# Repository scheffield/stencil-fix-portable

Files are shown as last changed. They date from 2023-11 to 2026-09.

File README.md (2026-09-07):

# Stencil Fix Portable

Stencil Fix Portable YouTube video (https://youtu.be/Am3ztQIkss0 "Stencil Fix Portable")

## Assembly
Perfboard top view
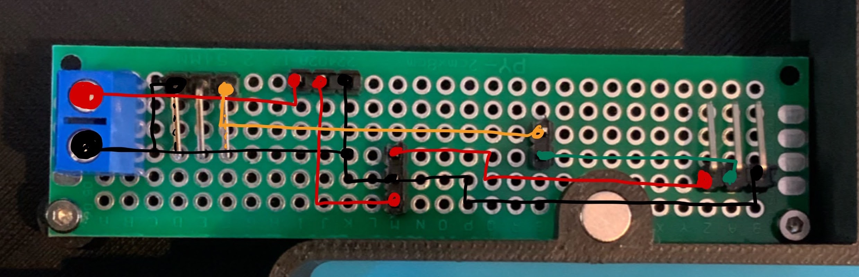
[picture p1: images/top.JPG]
Top view

View when soldering (flipped from the top view)
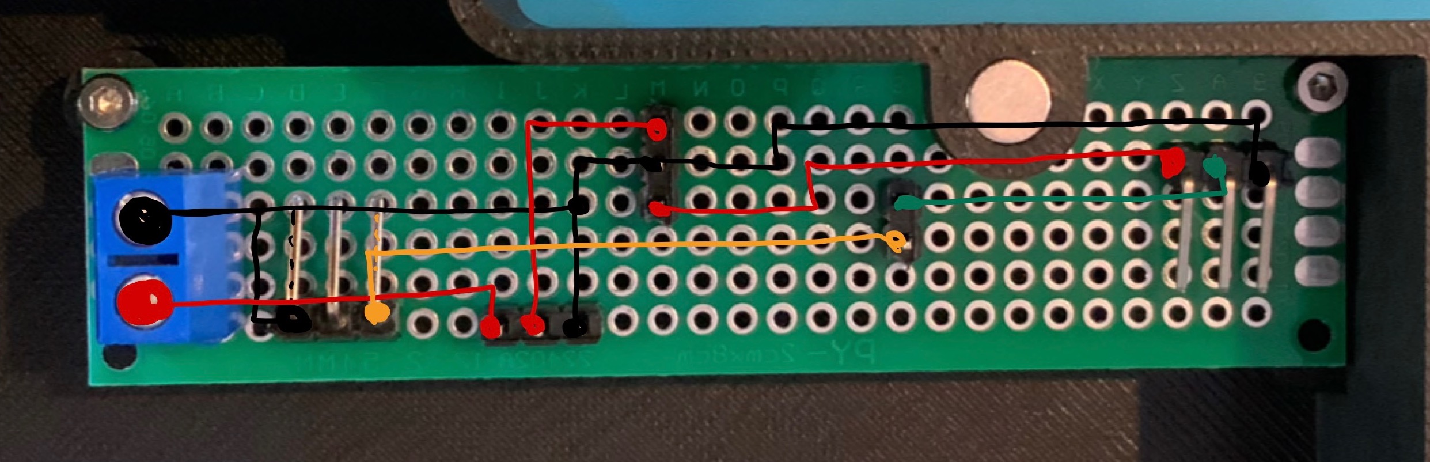
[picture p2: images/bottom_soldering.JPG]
Soldering view


## Stencil size

Use a **150 × 150 mm frameless stencil** with this setup. When ordering from JLCPCB, choose **Framework: No**. Under **Dimensions**, select **Custom Size** and set both **X** and **Y** to **150 mm**.

JLCPCB ordering form with Custom Size selected and X and Y both set to 150 mm

Choose stencil side and thickness to suit your PCB.

## BOM
| Part | Amount | Comment |
|---|---|---|
| M3\*4*4 heat-set insert | 4 | In base, holding screws for top |
| M2\*3*3.5 heat-set insert | 4 | In base, holding screws for perf board |
| M3*20 socket head screw | 8 | 4 holding top, 4 in lifter |
| M3*12 socket head screw | 4 | Holding motor |
| M2*4 socket head screw | 4 | holding perf board |
| [Spring 9.52\*15.8](https://www.ebay.com.au/itm/155259928566) (US: [3/8"\*3/4"](https://www.harborfreight.com/200-piece-assorted-spring-set-67562.html)) | 4 | 
| 18AWG Wire | 1 | wiring switch, battery and ESC |
| 22AWG Wire | 1 | wiring perf board |
| Perf board 80*20mm | 1 | |
| [QT Py RP2040](https://www.adafruit.com/product/4900) | 1 | |
| [Buck Converter board](https://www.adafruit.com/product/4739) | 1 | |
| [Drone Motor](https://www.phaserfpv.com.au/products/emax-eco-ii-series-2807-motor?variant=37115789213867) | 1 | lower kv == better |
| [Singe ESC](https://www.phaserfpv.com.au/products/aikonak3235a3-6s32bitdshot1200esc) | 1 | Should work with 3 cell LiPo |
| [3 cell LiPo](https://hobbiesdirect.com.au/nVision-11.1v-2200mAh-30C-LiPo-Battery-NVO1810) | 1 | |
| Amass XT60 Connector | 1 | Connecting battery to rocker switch |
| 2.54mm Single Row Male Header | 1 | Get a assortment like [this](https://www.amazon.com.au/dp/B01GY36RJY) |
| 2.54mm Pitch Single Row Right Angle | 1 | |
| Screw terminal 2.54mm pitch | 1 | |
| [Mini Female Spade - Blue](https://www.jaycar.com.au/mini-female-spade-blue-pack-of-8/p/PT4622) | 2 | Connect to the rocker switch |
| [10kΩ Potentiometer B10K](https://www.amazon.com.au/dp/B07XXWWXMC) | 1 | |

## Attribution
The impeller is generated with code from tytouf's [Centrifugal Impleller](https://www.thingiverse.com/thing:259773).

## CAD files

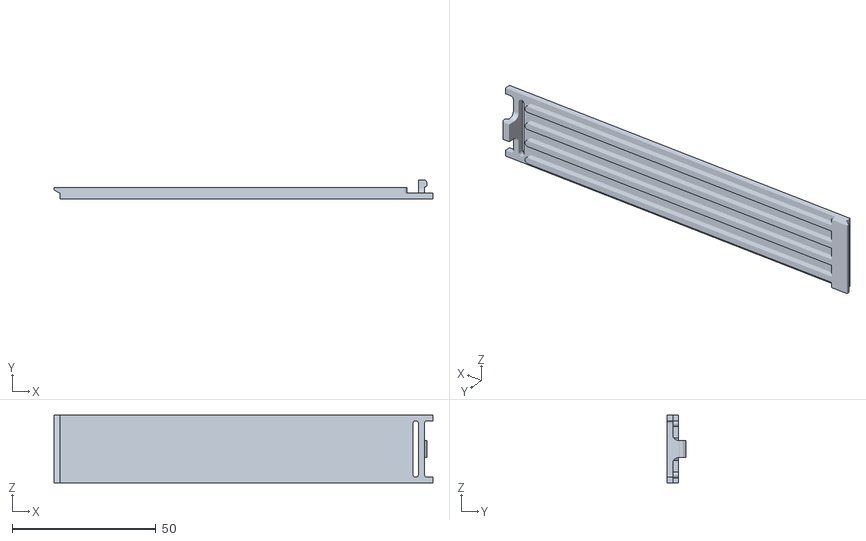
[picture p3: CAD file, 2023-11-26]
stl/base_battery_lid.stl
131.8 x 6.58 x 23.6

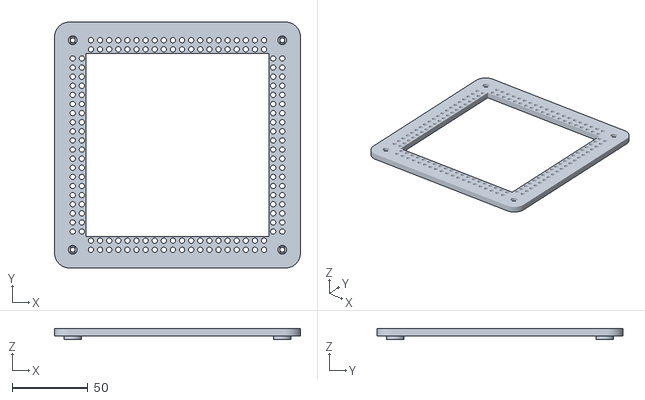
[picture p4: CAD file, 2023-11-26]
stl/lifter.stl
162.0 x 162.0 x 7.50

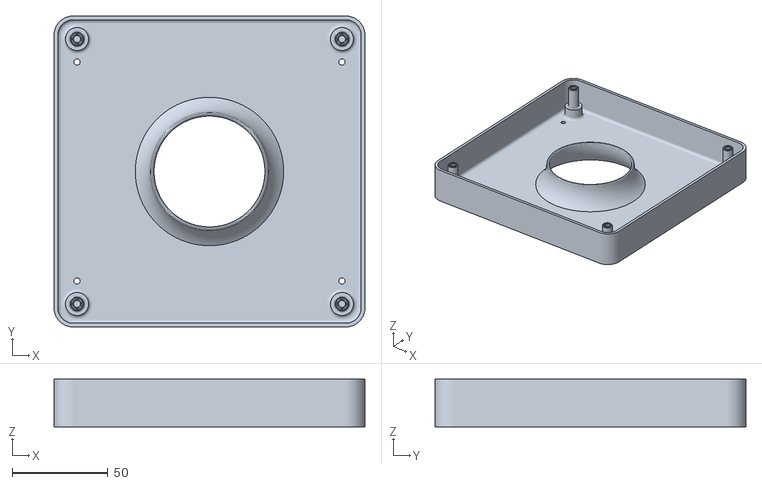
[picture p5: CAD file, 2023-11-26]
stl/top.stl
162.0 x 162.0 x 25.0

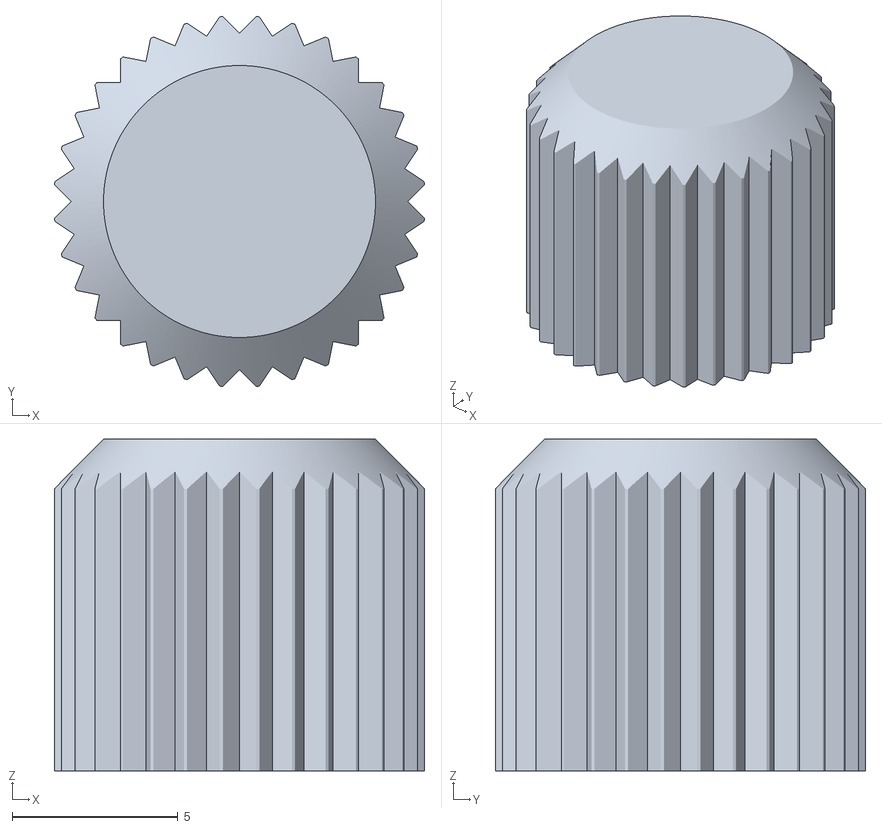
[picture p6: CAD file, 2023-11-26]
stl/pot_knob.stl
11.2 x 11.2 x 10.0

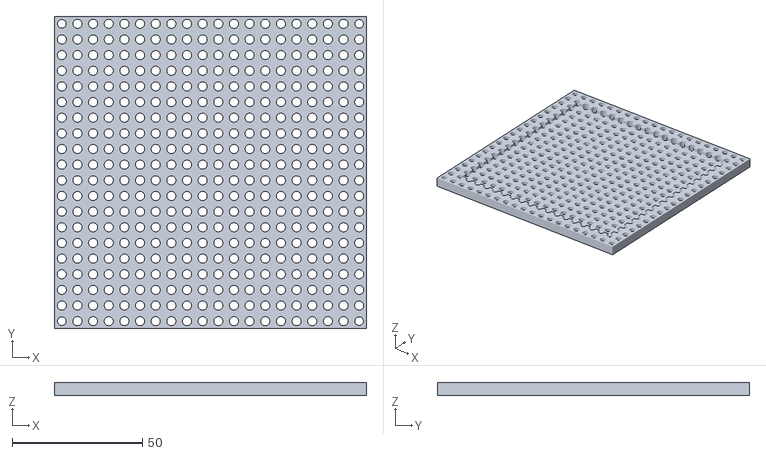
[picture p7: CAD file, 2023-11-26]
stl/pcb_holder.stl
119.6 x 119.6 x 5.00

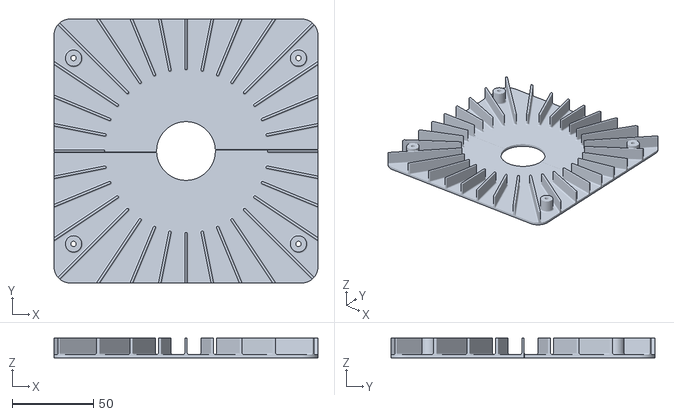
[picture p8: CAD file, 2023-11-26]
stl/electronics_lid.stl
162.0 x 162.0 x 12.0

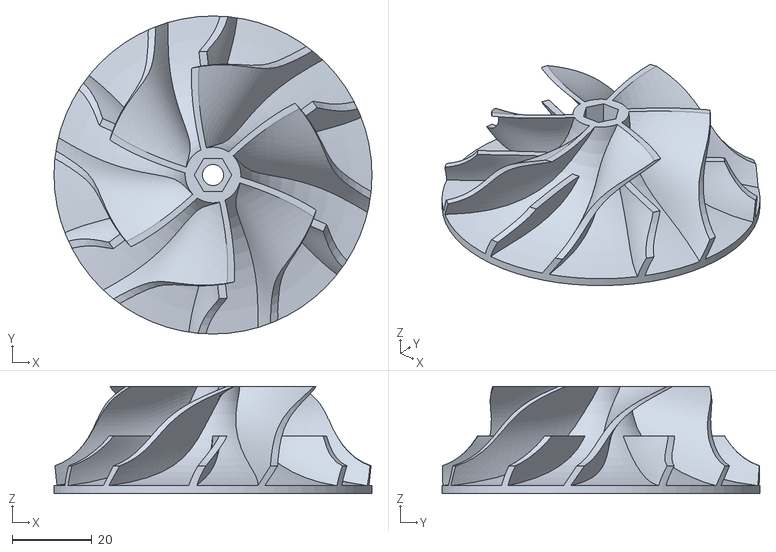
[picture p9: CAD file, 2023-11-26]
stl/impeller_ccw.stl
80.0 x 80.0 x 27.0

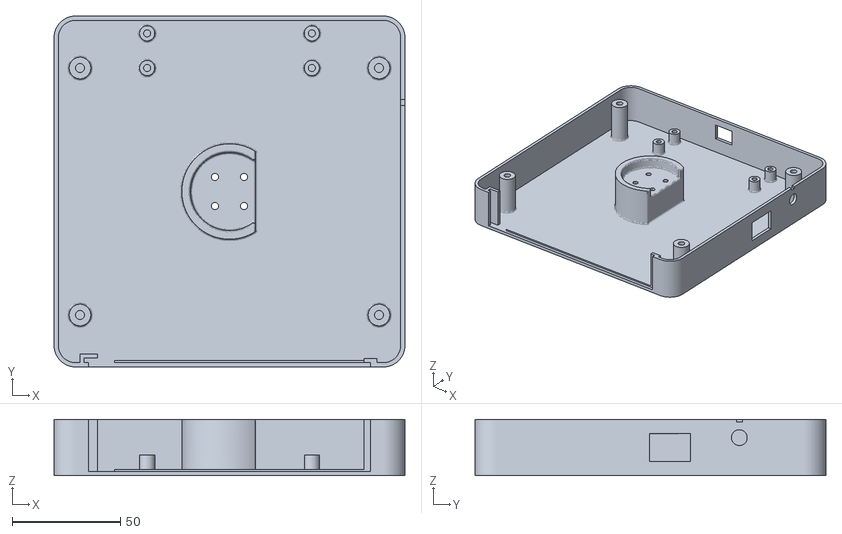
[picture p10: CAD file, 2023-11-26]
stl/base.stl
162.0 x 162.0 x 26.0

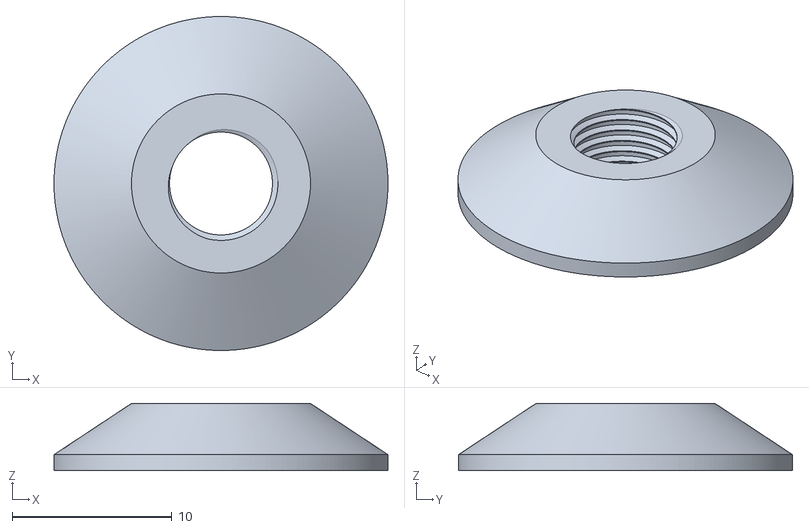
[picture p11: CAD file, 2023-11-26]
stl/pot_screw.stl
20.9 x 20.9 x 4.20

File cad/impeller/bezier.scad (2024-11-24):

//=====================================
// This is public Domain Code
// Contributed by: William A Adams
// 25 May 2011
//=====================================


//=======================================
//
//			 Functions
//
//=======================================

/*
	Bernstein Basis Functions

	For Bezier curves, these functions give the weights per control point.
	
*/
function BEZ03(u) = pow((1-u), 3);
function BEZ13(u) = 3*u*(pow((1-u),2));
function BEZ23(u) = 3*(pow(u,2))*(1-u);
function BEZ33(u) = pow(u,3);


// Calculate a singe point along a cubic bezier curve
// Given a set of 4 control points, and a parameter 0 <= 'u' <= 1
// These functions will return the exact point on the curve
function PtOnBez2D(p0, p1, p2, p3, u) = [
	BEZ03(u)*p0[0]+BEZ13(u)*p1[0]+BEZ23(u)*p2[0]+BEZ33(u)*p3[0],
	BEZ03(u)*p0[1]+BEZ13(u)*p1[1]+BEZ23(u)*p2[1]+BEZ33(u)*p3[1]];

// Given an array of control points
function PtOnBez(cps, u) = 
	[BEZ03(u)*cps[0][0]+BEZ13(u)*cps[1][0]+BEZ23(u)*cps[2][0]+BEZ33(u)*cps[3][0],
	BEZ03(u)*cps[0][1]+BEZ13(u)*cps[1][1]+BEZ23(u)*cps[2][1]+BEZ33(u)*cps[3][1],
	BEZ03(u)*cps[0][2]+BEZ13(u)*cps[1][2]+BEZ23(u)*cps[2][2]+BEZ33(u)*cps[3][2]];

// Calculate a point on a Bezier mesh
// Given the mesh, and the parametric 'u', and 'v' values
function PtOnBezMesh(mesh, uv) = PtOnBez(
	[PtOnBez(mesh[0], uv[0]), PtOnBez(mesh[1], uv[0]),
	PtOnBez(mesh[2], uv[0]), PtOnBez(mesh[3], uv[0])], 
	uv[1]);

// Given a mesh of control points, and an array that contains the 
// row and column of the quad we want, return the quad as an 
// ordered set of points.  The winding will be counter clockwise
function GetControlQuad(mesh, rc) = [ 
	mesh[rc[0]+1][rc[1]], 
	mesh[rc[0]][rc[1]], 
	mesh[rc[0]][rc[1]+1], 
	mesh[rc[0]+1][rc[1]+1]
];


// Given a mesh, and the 4 parametric points, return a quad that has the appropriate 
// points along the curve, in counter clockwise order
function GetCurveQuad(mesh, u1v1, u2v2) = [
	PtOnBezMesh(mesh, [u1v1[0],u2v2[1]]), 
	PtOnBezMesh(mesh, u1v1),
	PtOnBezMesh(mesh, [u2v2[0],u1v1[1]]), 
	PtOnBezMesh(mesh, u2v2)];

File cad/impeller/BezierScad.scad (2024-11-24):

/* 
  Bezier functions for OpenScad
  Generated from BezierScad.coffee from darwin at Fri May 10 2013 22:59:02 GMT-0700 (PDT)
  Supports Bezier interpolation with 1-8 controls
  Sources/Inspirations:
    http://en.wikipedia.org/wiki/Bézier_curve
    http://www.cs.mtu.edu/~shene/COURSES/cs3621/NOTES/spline/Bezier/bezier-der.html
    http://www.thingiverse.com/thing:8443

Copyright (c) 2013 Chad Kirby

Permission is hereby granted, free of charge, to any person obtaining a copy
of this software and associated documentation files (the "Software"), to deal
in the Software without restriction, including without limitation the rights
to use, copy, modify, merge, publish, distribute, sublicense, and/or sell
copies of the Software, and to permit persons to whom the Software is
furnished to do so, subject to the following conditions:

The above copyright notice and this permission notice shall be included in
all copies or substantial portions of the Software.

THE SOFTWARE IS PROVIDED "AS IS", WITHOUT WARRANTY OF ANY KIND, EXPRESS OR
IMPLIED, INCLUDING BUT NOT LIMITED TO THE WARRANTIES OF MERCHANTABILITY,
FITNESS FOR A PARTICULAR PURPOSE AND NONINFRINGEMENT. IN NO EVENT SHALL THE
AUTHORS OR COPYRIGHT HOLDERS BE LIABLE FOR ANY CLAIM, DAMAGES OR OTHER
LIABILITY, WHETHER IN AN ACTION OF CONTRACT, TORT OR OTHERWISE, ARISING FROM,
OUT OF OR IN CONNECTION WITH THE SOFTWARE OR THE USE OR OTHER DEALINGS IN
THE SOFTWARE.
*/


module BezLine(ctlPts, width = [1], resolution = 4, centered = false, showCtls = true) {
  hodoPts = hodograph(ctlPts);
  if (showCtls) {
    for (pt = ctlPts) {
      % translate([pt[0], pt[1], 0]) circle(1);
    }
  }
  if (resolution == 2) {
    if (centered) {
      polygon([
        PerpAlongBez(0/3, ctlPts, dist = BezI(0/3, width)/2, hodograph = hodoPts), PerpAlongBez(1/3, ctlPts, dist = BezI(1/3, width)/2, hodograph = hodoPts), PerpAlongBez(2/3, ctlPts, dist = BezI(2/3, width)/2, hodograph = hodoPts), PerpAlongBez(3/3, ctlPts, dist = BezI(3/3, width)/2, hodograph = hodoPts), PerpAlongBez(3/3, ctlPts, dist = BezI(3/3, width)/-2, hodograph = hodoPts), PerpAlongBez(2/3, ctlPts, dist = BezI(2/3, width)/-2, hodograph = hodoPts), PerpAlongBez(1/3, ctlPts, dist = BezI(1/3, width)/-2, hodograph = hodoPts), PerpAlongBez(0/3, ctlPts, dist = BezI(0/3, width)/-2, hodograph = hodoPts)
      ]);
    } else {
      polygon([
        PointAlongBez(0/3, ctlPts), PointAlongBez(1/3, ctlPts), PointAlongBez(2/3, ctlPts), PointAlongBez(3/3, ctlPts), PerpAlongBez(3/3, ctlPts, dist = BezI(3/3, width), hodograph = hodoPts), PerpAlongBez(2/3, ctlPts, dist = BezI(2/3, width), hodograph = hodoPts), PerpAlongBez(1/3, ctlPts, dist = BezI(1/3, width), hodograph = hodoPts), PerpAlongBez(0/3, ctlPts, dist = BezI(0/3, width), hodograph = hodoPts)
      ]);
    }
  } else if (resolution == 3) {
    if (centered) {
      polygon([
        PerpAlongBez(0/7, ctlPts, dist = BezI(0/7, width)/2, hodograph = hodoPts), PerpAlongBez(1/7, ctlPts, dist = BezI(1/7, width)/2, hodograph = hodoPts), PerpAlongBez(2/7, ctlPts, dist = BezI(2/7, width)/2, hodograph = hodoPts), PerpAlongBez(3/7, ctlPts, dist = BezI(3/7, width)/2, hodograph = hodoPts), PerpAlongBez(4/7, ctlPts, dist = BezI(4/7, width)/2, hodograph = hodoPts), PerpAlongBez(5/7, ctlPts, dist = BezI(5/7, width)/2, hodograph = hodoPts), PerpAlongBez(6/7, ctlPts, dist = BezI(6/7, width)/2, hodograph = hodoPts), PerpAlongBez(7/7, ctlPts, dist = BezI(7/7, width)/2, hodograph = hodoPts), PerpAlongBez(7/7, ctlPts, dist = BezI(7/7, width)/-2, hodograph = hodoPts), PerpAlongBez(6/7, ctlPts, dist = BezI(6/7, width)/-2, hodograph = hodoPts), PerpAlongBez(5/7, ctlPts, dist = BezI(5/7, width)/-2, hodograph = hodoPts), PerpAlongBez(4/7, ctlPts, dist = BezI(4/7, width)/-2, hodograph = hodoPts), PerpAlongBez(3/7, ctlPts, dist = BezI(3/7, width)/-2, hodograph = hodoPts), PerpAlongBez(2/7, ctlPts, dist = BezI(2/7, width)/-2, hodograph = hodoPts), PerpAlongBez(1/7, ctlPts, dist = BezI(1/7, width)/-2, hodograph = hodoPts), PerpAlongBez(0/7, ctlPts, dist = BezI(0/7, width)/-2, hodograph = hodoPts)
      ]);
    } else {
      polygon([
        PointAlongBez(0/7, ctlPts), PointAlongBez(1/7, ctlPts), PointAlongBez(2/7, ctlPts), PointAlongBez(3/7, ctlPts), PointAlongBez(4/7, ctlPts), PointAlongBez(5/7, ctlPts), PointAlongBez(6/7, ctlPts), PointAlongBez(7/7, ctlPts), PerpAlongBez(7/7, ctlPts, dist = BezI(7/7, width), hodograph = hodoPts), PerpAlongBez(6/7, ctlPts, dist = BezI(6/7, width), hodograph = hodoPts), PerpAlongBez(5/7, ctlPts, dist = BezI(5/7, width), hodograph = hodoPts), PerpAlongBez(4/7, ctlPts, dist = BezI(4/7, width), hodograph = hodoPts), PerpAlongBez(3/7, ctlPts, dist = BezI(3/7, width), hodograph = hodoPts), PerpAlongBez(2/7, ctlPts, dist = BezI(2/7, width), hodograph = hodoPts), PerpAlongBez(1/7, ctlPts, dist = BezI(1/7, width), hodograph = hodoPts), PerpAlongBez(0/7, ctlPts, dist = BezI(0/7, width), hodograph = hodoPts)
      ]);
    }
  } else if (resolution == 4) {
    if (centered) {
      polygon([
        PerpAlongBez(0/15, ctlPts, dist = BezI(0/15, width)/2, hodograph = hodoPts), PerpAlongBez(1/15, ctlPts, dist = BezI(1/15, width)/2, hodograph = hodoPts), PerpAlongBez(2/15, ctlPts, dist = BezI(2/15, width)/2, hodograph = hodoPts), PerpAlongBez(3/15, ctlPts, dist = BezI(3/15, width)/2, hodograph = hodoPts), PerpAlongBez(4/15, ctlPts, dist = BezI(4/15, width)/2, hodograph = hodoPts), PerpAlongBez(5/15, ctlPts, dist = BezI(5/15, width)/2, hodograph = hodoPts), PerpAlongBez(6/15, ctlPts, dist = BezI(6/15, width)/2, hodograph = hodoPts), PerpAlongBez(7/15, ctlPts, dist = BezI(7/15, width)/2, hodograph = hodoPts), PerpAlongBez(8/15, ctlPts, dist = BezI(8/15, width)/2, hodograph = hodoPts), PerpAlongBez(9/15, ctlPts, dist = BezI(9/15, width)/2, hodograph = hodoPts), PerpAlongBez(10/15, ctlPts, dist = BezI(10/15, width)/2, hodograph = hodoPts), PerpAlongBez(11/15, ctlPts, dist = BezI(11/15, width)/2, hodograph = hodoPts), PerpAlongBez(12/15, ctlPts, dist = BezI(12/15, width)/2, hodograph = hodoPts), PerpAlongBez(13/15, ctlPts, dist = BezI(13/15, width)/2, hodograph = hodoPts), PerpAlongBez(14/15, ctlPts, dist = BezI(14/15, width)/2, hodograph = hodoPts), PerpAlongBez(15/15, ctlPts, dist = BezI(15/15, width)/2, hodograph = hodoPts), PerpAlongBez(15/15, ctlPts, dist = BezI(15/15, width)/-2, hodograph = hodoPts), PerpAlongBez(14/15, ctlPts, dist = BezI(14/15, width)/-2, hodograph = hodoPts), PerpAlongBez(13/15, ctlPts, dist = BezI(13/15, width)/-2, hodograph = hodoPts), PerpAlongBez(12/15, ctlPts, dist = BezI(12/15, width)/-2, hodograph = hodoPts), PerpAlongBez(11/15, ctlPts, dist = BezI(11/15, width)/-2, hodograph = hodoPts), PerpAlongBez(10/15, ctlPts, dist = BezI(10/15, width)/-2, hodograph = hodoPts), PerpAlongBez(9/15, ctlPts, dist = BezI(9/15, width)/-2, hodograph = hodoPts), PerpAlongBez(8/15, ctlPts, dist = BezI(8/15, width)/-2, hodograph = hodoPts), PerpAlongBez(7/15, ctlPts, dist = BezI(7/15, width)/-2, hodograph = hodoPts), PerpAlongBez(6/15, ctlPts, dist = BezI(6/15, width)/-2, hodograph = hodoPts), PerpAlongBez(5/15, ctlPts, dist = BezI(5/15, width)/-2, hodograph = hodoPts), PerpAlongBez(4/15, ctlPts, dist = BezI(4/15, width)/-2, hodograph = hodoPts), PerpAlongBez(3/15, ctlPts, dist = BezI(3/15, width)/-2, hodograph = hodoPts), PerpAlongBez(2/15, ctlPts, dist = BezI(2/15, width)/-2, hodograph = hodoPts), PerpAlongBez(1/15, ctlPts, dist = BezI(1/15, width)/-2, hodograph = hodoPts), PerpAlongBez(0/15, ctlPts, dist = BezI(0/15, width)/-2, hodograph = hodoPts)
      ]);
    } else {
      polygon([
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

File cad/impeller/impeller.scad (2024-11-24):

//===================================== 
// This is Public Domain Code
// Contributed by: Christophe Augier
// 27 February 2014
//=====================================

// from https://www.thingiverse.com/thing:259773/files

use <Renderer.scad>;
use <BezierScad.scad>;

$fn=64; // general precision (used for the extruded body)
blade_precision = 20; // set to higher (height) for a better precision, keep low (4) for faster rendering

height = 25;  // height of the impeller
radius = 40;  // radius of the impeller
inlet_size = 20;  // size (radius) of the inflow
outlet_size = 5;  // size (height) of the outflow
inner_radius = 7;  // radius for the center shaft
control_point = [1, 4];  // control point to change curve
use_head = false;  // render a spherical head at the tip of the impeller
thickness = 2; // thickness of the base

n_blades = 6;  // number of blades
main_blade_height = height;  // height of main blades
blade_thickness = 2;  // blade thickness

use_splitters = true;  // render splitter blades
splitter_blade_height = height * 0.5; // height of splitter blades
splitter_offset_angle = -3;  // add angle offset relative to main blade

// The following sets of points define the blade profiles.
// You should only need to edit the last value (z) to change
// the curve of the blade.
// The first line is the bottom of the blade, the last line the
// top of the blade.

main_blade_points = [
  [[0, 0, 0],
   [radius * 2 / 4, 0, 0],
   [radius * 3 / 4, 0, 5],
   [radius, 0, 10]],
  [[0, main_blade_height * 2 / 4,0],
   [radius * 2 / 4, main_blade_height * 2 / 4, 0],
   [radius * 3 / 4, main_blade_height * 2 / 4, 0],
   [radius, main_blade_height * 2 / 4, 0]],
  [[0, main_blade_height * 3 / 4,0],
   [radius * 2 / 4, main_blade_height * 3 / 4, 0],
   [radius * 3 / 4, main_blade_height * 3 / 4, 0],
   [radius, main_blade_height * 3 / 4, 0]],
  [[0, main_blade_height, 0],
   [radius * 2 / 4, main_blade_height, -20],
   [radius * 3 / 4, main_blade_height, -20],
   [radius, main_blade_height, -20]]];

splitter_blade_points = [
  [[0, 0, 0],
   [radius * 2 / 4, 0, 0],
   [radius * 3 / 4, 0, 4],
   [radius, 0, 4]],
  [[0, splitter_blade_height * 2 / 4, 0],
   [radius * 2 / 4, splitter_blade_height * 2 / 4, 0],
   [radius * 3 / 4, splitter_blade_height * 2 / 4, 2],
   [radius, splitter_blade_height * 2 / 4, 2]],
  [[0, splitter_blade_height * 3 / 4,0],
   [radius * 2 / 4, splitter_blade_height * 3 / 4, 0],
   [radius * 3 / 4, splitter_blade_height * 3 / 4, -2],
   [radius, splitter_blade_height * 3 / 4, -2]],
  [[0, splitter_blade_height, 0],
   [radius * 2 / 4, splitter_blade_height, 0],
   [radius * 3 / 4, splitter_blade_height, -4],
   [radius, splitter_blade_height, -4]]];

// Uncomment the two following lines to render the main blade
// and the splitter blade profiles.
//main_blade();
//splitter_blade();

// Uncomment the two following lines to render the base body
// and the upper body profiles.
//base();
//upper_body();

// Uncomment the following line to render the impeller.
impeller();

module main_blade() {
 render()
  rotate([90, 0, 0])
   DisplayBezSurface(main_blade_points, 
	 colors=[[1,0,0],[1,1,0],[0,1,1],[0,0,1]],
	 steps=blade_precision, thickness=blade_thickness);
}

module splitter_blade() {
 render()
  rotate([90, 0, 0])
   DisplayBezSurface(splitter_blade_points, 
	 colors=[[1,0,0],[1,1,0],[0,1,1],[0,0,1]],
	 steps=blade_precision, thickness=blade_thickness);
}

module base() {
 union() {
  rotate_extrude()
   union() {
    polygon([[0, -thickness], [0, height],
             [inner_radius, height],
             [inner_radius, 0],
             [radius, 0],
             [radius, -thickness]]);
    translate([inner_radius, 0, 0])
     BezArc([[0, height], control_point,
             [radius-inner_radius, 0]], [0, 0],
             steps=12, height=0);
   }
  if (use_head) {
    translate([0, 0, height]) sphere(r=inner_radius);
  }
 }
}

module upper_body() {
 margin = 10;
 //projection(cut=true)rotate([90,0,0]) // to export the inlet as svg
 rotate_extrude()
  translate([inner_radius+inlet_size, outlet_size, 0])
   difference() {
    polygon([[0, 0], [0, height+margin],
             [radius-inner_radius-inlet_size+margin, height+margin],
             [radius-inner_radius-inlet_size+margin, -outlet_size-margin],
             [radius-inner_radius-inlet_size, -outlet_size-margin],
             [radius-inner_radius-inlet_size, 0]]);
    BezArc([[0, height], control_point,
            [radius-inner_radius-inlet_size, 0]], [0, 0],
            steps=12, height=0);
  }
}

module impeller() {
 difference() {
  union() {
   base();
   for (i = [0:n_blades]) {
    rotate(i * 360 / n_blades, [0, 0, 1])
     main_blade();
   }
   if (use_splitters) {
    for (i = [0:n_blades]) {
     rotate((i+0.5) * 360 / n_blades + splitter_offset_angle, [0, 0, 1])
      splitter_blade();
    }
   }
  }
  upper_body();
 }
}

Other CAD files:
stl/impeller_cw.stl
cad/impeller/maths.scad
cad/impeller/Renderer.scad
cad/impeller_case_3_motor.f3d

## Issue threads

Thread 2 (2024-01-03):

Clarification re: ccw and cw impeller

coryalder, 2024-01-03:
Hi! Love this design - I was just about to print the shop-vac version of this when I found your most recent video!

Just wondering if you could clarify the meaning of the CCW and CW impeller models. It doesn't look like I need both, which should I print, and when?

scheffield, 2024-01-03:
Hey there. I'm glad you find it useful 😄 .

CW standards for clockwise and CCW for counter clockwise. So print what ever direction your motor spins in.

analogmonster, 2024-11-29:
Just wanted to add, you can change the direction an ESC drives a motor by swapping 2 of the 3 wires between the ESC and motor.  But best practice would be to print an impeller according to what direction the thread is cut on the motor.  You want the motor to spin the direction that would tighten the impeller onto the shaft, otherwise the motor could eventually unthread the impeller just through torque

Closed 2024-11-24.

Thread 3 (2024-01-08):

Larger size

mandreko, 2024-01-08:
I currently have several PCBs where my stencil is 190x190mm. I'm going to build this up, and see how well it works with a stencil that is larger than the base (the PCB is smaller though).

I'd be curious if there was any interest or issues creating a 200x200mm or so version of this? If I can get some free time, I may modify the CAD to do this myself, but didn't know if you had any experience with it already. I'd be curious if the current motor and impeller could handle the size difference or not.

scheffield, 2024-01-13:
Hey Matt, I was initially considering to make the model parameterised so that larger and smaller version could be created but it wasn't straight forward. Maybe I give it a try once I find some time.

Regarding a version that is much larger than the current one: the lid will most likely sag and some extra support would be needed.

mandreko, 2024-01-16:
The lid sag is a super valid concern. I hadn't thought of it either. Thanks for thinking of it.

clazarowitz, 2024-11-17:
Making a 200mmx200mm version was pretty straightforward, but it did involve some changes.  Sag was absolutely an issue.  I suspect PLA might have been better, or carbon filled PLA, but the print times were horrible, so I laser cut acrylic instead.  Its quite stiff.  I made the lid from "3/16" acrylic (5mm).  I made the lip for the lid from the same stuff.  Other than cutting out the holes and the outline, I made a light engraved line to show me where to glue the lip.  For the lifter, I used 6mm acrylic.  I cut all the holes including an 11.5mm hole for the lifter points.  Then I glued 6mm acrylic to 2mm acrylic and cut plugs to make the alignment pins.  I cut a 3.2mm hole straight through each one, and engraved a hole to enclose the socket head cap screw.  This was more than stiff enough to prevent sag.  Additionally, I wanted the motor quick, so I used a slightly smaller one 1800KV and ran it off a 6S pack (well, a 24V DC power supply).  I needed to go a little past half throttle to get enough hold down force for the stencil, but I suspect that is because I accidentally ordered by stencils wav oversized.  I cut them with aircraft shears, and still oversized, but I think it caused a slight warping.  I also think re-adding the outer layer of holes would help a bunch for such oversized boards.  The main problem I have is it really needs some longer springs.  These just barely compress and the solder paste held the stencil down to the board.  I had to manually lift the lifter, and even then, getting the stencil off without smearing (much) was a trick!  a

I'm more than willing to share files, but I prefer inventor to fusion, so when I remodeled everything I used inventor.  Fusion can import ipt files, but I don't think its any better than step files.  I could...probably...redo it in fusion.  I just find the multiple parts in one file frustrating and having to close the inspect tool every time I want to start a new measurement infuriating, so I gave up and went back to inventor (not free).  I should have saved my settings for the alignment pins, but I was adjusting in lightburn.  I'm probably going to redo it again with the last line of holes on the lifter, so maybe I'll write down the actual settings this time.  I am using a 2.5" err....what is that, 63.5mm lens on the laser.  There will be variances in kerf width even between lenses, but the same class of lens should be pretty close :) I also would have to export my dxf's since I modified the sketches for kerf width.

So what I made is recognizable as a stencil fix portable, its very different.  I'll open another issue for this, but my one suggestion would be to make the motor mount a separately printed item that is bolted to the main frame to account for different bolt hole patterns and motor diameters.  I used a 2306.5 motor so I had to move the whole mount up a bit and make the enclosing circle a bit smaller, it used a 16mm pattern rather than a 19mm pattern.  The motor has plenty of power even for a 200mm version!

Closed 2025-03-05.

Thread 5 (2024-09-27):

Double sided pcb

Exotelis, 2024-09-27:
Hey,

great video and great project. Have you any ideas about double sided pcbs? I also printed some stencil holder but none is accurate enough for 0402 components and I really like the vacuum idea ❤️

clazarowitz, 2024-11-17:
He won't be able to make a generic holder for backside components.  You're going to need to learn a little fusion 360.  Its free, and there are tons of tutorials.  3d models of your board can be exported with FreeCAD.  So one option is to export your board, i'd probably scale it by ~10% to account for tolerances, cut out your current board outline again, then use a boolean operation in Fusion.  You make have to make a taller lifter and board holder though.

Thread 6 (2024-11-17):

Make motor mount a separate item

clazarowitz, 2024-11-17:
I used a 2306.5 motor which still has plenty of power.  It would be nice if the motor mount was an item that was bolted to the frame so different sized motors could be used.  If I have to reprint my base, my plan is to do this.  So far though, I don't think I need to worry about it.

analogmonster, 2024-11-29:
In the CAD folder, there are .step files and .f3d files.  I have imported the [stencil_fix_portable.f3d](https://github.com/scheffield/stencil-fix-portable/blob/main/cad/stencil_fix_portable.f3d) file into fusion 360 and I will be customising the base.  It's truly open source, not just stl files but files you can easily work with.  There is even a free fusion 360 licence for non commerical use, but good cad programs can import native files from other manufacturers - solidworks can open f3d files too

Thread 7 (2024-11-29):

BOM missing rocker switch

analogmonster, 2024-11-29:
Hi, thanks for the great project.  I'm getting the impeller resin printed by a friend but will be FDM for the rest.  The BOM is missing which specific rocker switch you used.

Thanks so much for providing .f3d files!  I'm just going to customise the base to fit electronics I have in stock, but others may need to know what part you used

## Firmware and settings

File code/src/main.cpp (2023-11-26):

#include <Arduino.h>
#include <Adafruit_NeoPixel.h>
#include <Servo.h>

class LowPass {
  private:
    float _previousPrefilteredAnalog;
    unsigned long _previousMicros = 0;
  public:
    float RCus;
    LowPass(float _RCus) : RCus(_RCus) {}
    float step(float prefilteredAnalog) {
      if (_previousMicros == 0) {
        _previousMicros = micros();
        _previousPrefilteredAnalog = prefilteredAnalog;
        return prefilteredAnalog;
      }
      unsigned long now = micros();
      unsigned long dt = now - _previousMicros;
      float alpha = dt / (RCus * dt);
      _previousMicros = now;
      _previousPrefilteredAnalog += alpha * (prefilteredAnalog - _previousPrefilteredAnalog);
      return _previousPrefilteredAnalog;
    }
};

// How many internal neopixels do we have? some boards have more than one!
#define NUMPIXELS 1
Adafruit_NeoPixel pixels(NUMPIXELS, PIN_NEOPIXEL, NEO_GRB + NEO_KHZ800);

Servo servo;

// low pass filter with an RC time constant of 40us
LowPass lowPass(40);

void setup() {
  Serial.begin(115200);

#if defined(NEOPIXEL_POWER)
  // If this board has a power control pin, we must set it to output and high
  // in order to enable the NeoPixels. We put this in an #if defined so it can
  // be reused for other boards without compilation errors
  pinMode(NEOPIXEL_POWER, OUTPUT);
  digitalWrite(NEOPIXEL_POWER, HIGH);
#endif

  pixels.begin(); // INITIALIZE NeoPixel strip object (REQUIRED)
  pixels.setBrightness(127);

  pinMode(A2, INPUT);
  analogReadResolution(12);

  servo.attach(A3, 1100, 1900);
  servo.writeMicroseconds(1500);
}

void loop() {
  int pot = analogRead(A2);

  // map pot to an HSV value that is between 240 deg and 360 deg of the color wheel.
  pixels.fill(pixels.ColorHSV(map(pot, 0, 4095, (pow(2, 16) - 1) * 240/360, pow(2, 16) - 1), 255, 255));
  pixels.show();

  servo.writeMicroseconds(lowPass.step(map(pot, 0, 4095, 1200, 2000)));

  delay(20);
}

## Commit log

2023-11-26 initial files
    [base.stl, base_battery_lid.stl, electronics_lid.stl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]
2023-12-20 Update README.md
    correct spring dimensions and count and added similar kit from USA retailer
2024-11-24 Adding impeller code and refernece to original
    [BezierScad.scad, Renderer.scad, bezier.scad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]
2026-09-07 Document the 150 × 150 mm stencil size (#11)
    * docs: document stencil size and JLCPCB order details
    * docs: show custom stencil size in the ordering form
    * docs: simplify stencil guidance after review
2026-10-25 Correct BOM spring length to 19 mm (#12)
2026-10-25 Document how to adapt the holder for double-sided PCBs (#13)
2026-10-25 Align lid guide holes with the 138 mm lifter pattern (#14)
2026-10-25 Document the KCD1-102 rocker switch (#15)
